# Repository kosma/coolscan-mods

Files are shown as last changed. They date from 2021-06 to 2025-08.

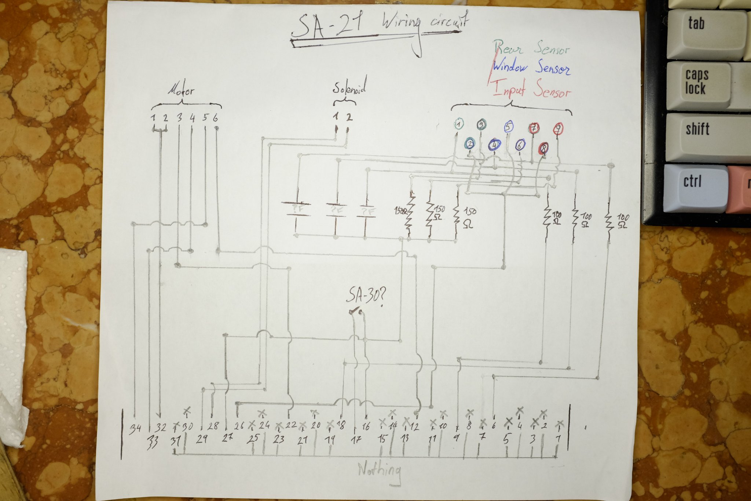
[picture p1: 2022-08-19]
doc/sa-21-30-schematic.jpg

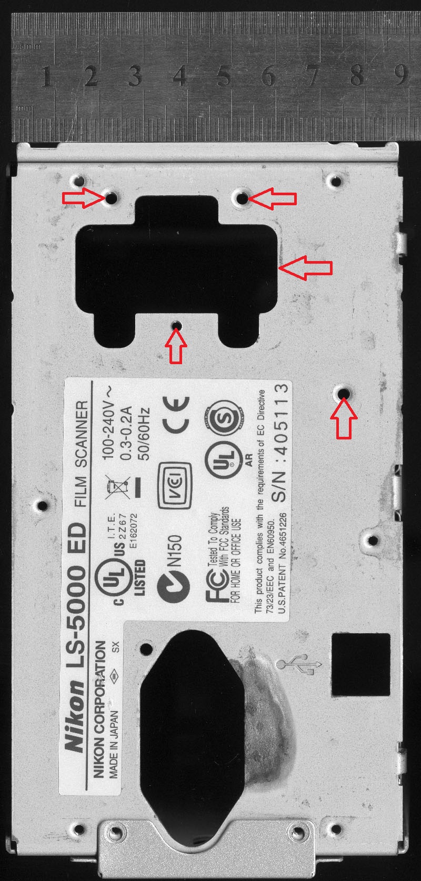
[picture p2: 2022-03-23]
hole/Modified.jpg

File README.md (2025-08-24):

# Nikon Coolscan modification project

## Adapter compatibility chart

| | **SA-30**  | **SF-200**  | **SF-210**  |
|---|---|---|---|
| **LS-40** | ✅ | ✅ | ✅ |
| **LS-50** | ✅ | ✅ | ✅ |

## Background

This project aims to extend old and unsupported Nikon Coolscan scanners.
Currently it allows owners of those scanners to unlock the ability to scan
full film rolls (using SA-30) and batch scan slides (using SF-210) on
Nikon Coolscan LS-40 and LS-50 (known as Coolscan IV and Coolscan V in
some markets).

Why? Because Nikon artificially crippled the LS-40 and LS-50 by removing
the ability to batch-scan, for no reason other than corporate greed and
market segmentation. All the logic needed to support SA-30 and SF-210 on
those scanners is already in place - it is just artificially disabled to
placate the finance and marketing.

Now, twenty years later, we can finally lift those artificial limitations
and enjoy the full power of these scanners.

## Requirements

* At the moment, this firmware is only available for LS-40 and LS-50.
* You need a 64-bit system to run the firmware updater.
* You need Vuescan drivers for the updater to work. I have not tested them
  on any other drivers. It *might* work with Nikon drivers.
* You must not have any other scanners connected during the update process.
* You must not have any scanning software running during the update process.
* For scanning entire rolls of film you need a hole cut in the back of
  the scanner. Trying to load an entire roll without the hole cut will
  cause physical damage to the film and/or scanner. The hole is not needed
  for bulk slide scanning with SF-200/SF-210.

## Instructions

1. Download the latest firmware package from the [Releases](https://github.com/kosma/coolscan-mods/releases) section and unpack it.
2. Connect your LS-40 or LS-50 over USB. Turn on the scanner.
3. Double-click `coolscan-updater.exe` and wait for the process to complete.
   As with all firmware updates, do NOT interrupt it until it says it's done.
   You might get a SmartScreen warning - it's a false positive. Check the file
   on VirusTotal if you're suspicious.
4. Turn the scanner off and on again.
5. Congratulations! Your scanner can now accept SA-30 and SF-210.

There is a bit more of mechanical work involved if you want to scan long
strips of film (longer than six frames, and up to 40 frames):

1. Cut a hole in the back of the scanner. This requires extensive disassembly
   of the scanner, as all electronic and mechanical components inside have to
   be removed before you can safelly cut/drill an opening.
   Do **NOT** attempt to cut the hole with the components still inside - getting
   *any* metal shavings inside the scanner pretty much dooms it to fail sooner
   than later.

   For cutting the opening, use [these guides](hole/) - make sure to print
   at 100% scale! The shape of the opening accommodates a standard
   LS-4000/LS-5000 back door and a spool holder; if you don't want to install
   them (you really don't need it), you can make the shape of the opening much
   simpler. On my scanner, I used a drill and a hacksaw - the results are
   not pretty, but it works like a charm.
   
   See [Gleb's website](http://www.shtengel.com/gleb/nikon_coolscan_4000_disassembly_and_scanhead_gear_repair.htm)
   for important disassembly notes.

2. Modify your SA-21 to be an SA-30 - the conversion process is described in
   many places on the internet, e.g. [Gleb's website](http://www.shtengel.com/gleb/converting_nikon_sa21_to_sa30.htm).
   It involves nothing more than installing/soldering one jumper.

**Warning:** At the moment the SA-30 support on LS-40 is somewhat broken -
the adapter is correctly identified but you can't scan more than six frames.

In the future I will also offer 3D-printable designs for the film door and
front and rear takeup spools - but those projects are still in development.
In the meantime, consider the absolutely stunning [full roll conversion kit](https://www.etsy.com/pl/listing/949217792/nikon-4000ed-and-5000ed-full-roll)
that should also fit your modded LS-40 or LS-50.

## Risks

There are a few risks involved with installing and using modified firmware:

1. If the firmware update process goes wrong, your scanner might be left in
   a non-operational (bricked) state. In most cases you can recover from this
   by simply restarting the update procedure - but in rare cases it might be
   required to desolder the FLASH chip from the mainboard and reprogram it in
   an external programmer (e.g. TL866II). Such services are commonly offered
   by respectable electronics repair shops for a modest fee. Full firmware
   dumps are provided for this purpose in the [dumps](dumps/) directory.

2. Using the unsupported LS-30 and SF-210 adapters might cause some components
   to wear out faster. I have not identified any potential components that are
   not fit to handle a bulk adapter, but again - I might have missed something.

3. Running SA-30 with long strips of film without cutting a hole in the back
   of the scanner will cause physical damage... I don't think I have to explain
   why. As a precaution, do *not* perform the SA-21 to SA-30 conversion until
   you have the hole cut.

## Technical documentation

This information is only relevant for people working on scanners - be it modders
or repairmen. It is of not much use to general public.

* [Technical information about the mod](doc/mod.md)
* [Hardware overview](doc/hardware.md)
* [SA-21/SA-30 pinout](doc/sa-21-30.md)
* [Firmware overview](doc/firmware.md)
* [Communication protocol](doc/protocol.md)
* [Firmware updates](doc/updates.md)
* [Service Manuals](manuals/)
* [Datasheets](datasheets/)
* [Firmware dumps](dumps/)
* [Firmware reflashers](reflashers/)

## Acknowledgements

This project has been made possible thanks to some great people:

* [Gleb Shtengel](http://www.shtengel.com/gleb/index.htm) - provided knowledge, firmware dumps, USB dumps, and parts
* [Kilian Dolan](https://github.com/arahowerya) - solved the six frame mystery ([issue #4](https://github.com/kosma/coolscan-mods/issues/4))
* Victor Gerasimov - provided knowledge, ideas, and firmware dumps
* Paulo Meireles - provided hardware, inspiration, and smiles
* Graeme Hardie - provided wisdom on the value of shipping 32-bit executables
* [Nikon Coolscan Users](https://www.facebook.com/groups/1514948298527146) - provided a fantastic captive audience for my shenanigans
* [SANE](https://gitlab.com/sane-project/backends/-/blob/master/backend/coolscan3.c) - provided bad but working open driver implementation
* [Служба НТИ](https://www.snti.ru/) - provided cheap ISO/IEC standards
* Frank Phillips - said he's skeptical, giving me the best motivation possible: spite

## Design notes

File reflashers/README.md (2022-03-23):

# Firmware Reflashers

These are original Nikon firmware updater programs modified to allow reflashing -
that is, installing the same version of firmware that is already present. This can
help recover from corrupted firmware - a failure mode found in many scanners out
in the wild. Symptoms of this failure are:

* The scanner turns on and the LED lights up green immediately.
* The scanner is visible in the operating system.
* The scanner, nevertheless, does not *scan*.

The idea for those reflashers came from Gleb Shtengel, and he confirmed their
utility in fixing at least *some* of the faulty boards.

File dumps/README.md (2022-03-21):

# Firmware Dumps

This directory contains unmodified firmware dumps, to be used in case the original
firmware gets corrupted and the scanner must be repaired.
Use a FLASH programmer like TL866 to program those dumps into chips. It's *not*
possible to restore such a dump over USB, and as such the dumps are of limited use,
mostly to professional scanner repairmen.

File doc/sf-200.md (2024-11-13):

# SF-200

## Pinout

Measured by John Dykstra.  Connector model is Honda MR-34F.

| **Name** | **Pin** | **SF-200** |
|---|---|---|
| LED1 | 1 | Front panel LED |
| LED2 | 2 | Front panel LED |
| M-WSIG2  | 3 | n/c |
| M-RSIG2  | 4 | n/c |
| MSW10 | 5 | Ground (Adapter Bit #1) |
| MSW6 | 6 | n/c |
| MSW2 | 7 | Switch; closed = home position |
| MSW4 | 8 | n/c |
| MSW16 | 9 | n/c |
| MSW17 | 10 | n/c |
| MSW8 | 11 | n/c |
| MT3_B/ | 12 | n/c |
| MGND | 13 | n/c |
| M-WSIG1  | 14 | n/c |
| M-RSIG1  | 15 | n/c |
| MSW9 | 16 | Ground (Adapter Bit #0) |
| MSW11 | 17 | n/c (Adapter Bit #2) |
| MSW5 | 18 | n/c |
| MSW3 | 19 | Switch; open = limit position |
| MSW14 | 20 | n/c |
| MSW7 | 21 | n/c |
| MT3_A/ | 22 | n/c |
| M+5V | 23 | n/c |
| MAGND | 24 | n/c |
| M+15V | 25 | n/c |
| +5V | 26 | n/c |
| DGND | 27 | Ground (to switches) |
| MT4_1 | 28 | Motor |
| MT4_2 | 29 | Motor |
| MT5_1 | 30 | n/c |
| MT5_2 | 31 | n/c |
| +15V | 32 | n/c |
| MT3_A | 33 | n/c |
| MT3_B | 34 | n/c |

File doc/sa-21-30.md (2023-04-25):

# SA-21/SA-30

## Pinout

Measured by Mattia Stellacci, verified by Kosma Moczek. To see the schematic,
[click here](sa-21-30-schematic.jpg). Connector model is Honda MR-34F.

| **Name** | **Pin** | **SA-21** |
|---|---|---|
| LED1 | 1 | n/c |
| LED2 | 2 | n/c |
| M-WSIG2  | 3 | n/c |
| M-RSIG2  | 4 | n/c |
| MSW10 | 5 | Adapter Bit #1 (n/c) |
| MSW6 | 6 | Input Sensor |
| MSW2 | 7 | n/c |
| MSW4 | 8 | n/c |
| MSW16 | 9 | Rear Sensor |
| MSW17 | 10 | n/c |
| MSW8 | 11 | n/c |
| MT3_B/ | 12 | Film motor B- |
| MGND | 13 | n/c |
| M-WSIG1  | 14 | n/c |
| M-RSIG1  | 15 | n/c |
| MSW9 | 16 | Adapter Bit #0 (connected to DGND on SA-30, n/c on SA-21) |
| MSW11 | 17 | Adapter Bit #2 (connected to DGND) |
| MSW5 | 18 | Window Sensor |
| MSW3 | 19 | n/c |
| MSW14 | 20 | n/c |
| MSW7 | 21 | n/c |
| MT3_A/ | 22 | Film motor A- |
| M+5V | 23 | n/c |
| MAGND | 24 | n/c |
| M+15V | 25 | n/c |
| +5V | 26 | Sensor +5V |
| DGND | 27 | Ground (Digital/Sensors) |
| MT4_1 | 28 | Solenoid+ (Physically fixes adapter in scanner during use)|
| MT4_2 | 29 | Solenoid- (Physically fixes adapter in scanner during use)|
| MT5_1 | 30 | n/c |
| MT5_2 | 31 | n/c |
| +15V | 32 | Film motor center tap |
| MT3_A | 33 | Film motor A+ |
| MT3_B | 34 | Film motor B+ |

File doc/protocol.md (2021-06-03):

# Communication protocol

All Coolscans use SCSI internally - even the Firewire/USB ones.
The scanners operate using SGC-2 (SCSI Graphics Commands) with some
proprietary extensions in the form of extra opcodes. Those opcodes
can be inferred from the firmware code (SCSI dispatch tables) and/or
SANE `coolscan3.c` driver (which contains some important nuggets of
knowledge, especially about USB communication protocol).

## SCSI scanners

The flavor of SCSI is SCSI-2. The parallel bus is 8-bit and runs at 10MHz,
giving an effective transfer rate of 10MB/s or 80Mbit/s. The bus is
single-ended and operates at TTL voltage levels, making interfacing
from a simple microcontroller quite possible.

See the [Wikipedia article](https://en.wikipedia.org/wiki/Parallel_SCSI)
for a timeline of Parallel SCSI evolution.

# FireWire scanners

The protocol used is [SBP-2](https://en.wikipedia.org/wiki/Serial_Bus_Protocol_2).
This is a direct SCSI transport for Firewire devices, meaning very little
to no extra translation is needed.

# USB scanners

The USB scanners use extra framing commands to communicate SCSI phase and
sense data over USB. They use a simple bulk interface consisting of one
Bulk-Out endpoint and one Bulk-In endpoint. This makes them suitable to be
used with Windows' `usbscan.sys` driver, since the following is enough to
perform all communication with the scanner - no extra syscalls are needed:

```c
CreateFile('\\\\.\\usbscan0', OPEN_EXISTING...);
WriteFile(hScanner, data, len);
ReadFile(hScanner, data, len);
```

Based on reading the SANE source code (`coolscan3.c`) and sniffing
Vuescan's communication, the following protocol has been established:

1. Send the SCSI command block.
2. Query the current SCSI phase by sending `0xD0`.
3. Receive the status byte that indicates the current phase.
4. Perform read/write depending on the phase.
5. Once phase indicates the command has completed, read
   the SENSE data by sending `0x06` and reading 8 bytes.

The intricacies of this protocol are not yet known to me but the above
information is enough for performing basic communication with success.

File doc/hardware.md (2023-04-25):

# Hardware overview

## CPU

The CPU used in all Coolscans is H8/3003. The CPU operates in Advanced Mode
(24-bit address bus). It is supported in IDA as "Hitachi H8/300H advanced".

## Peripheral connections

The scanner contains multiple address/data buses, with ASIC sitting in the
middle of it all. Despite of this complexity, all peripherals (including
LUT RAM, USB controller, etc.) can be directly accessed from the CPU.
The ASIC takes care of asserting the correct Chip Select lines and access
arbitration.

For exact connection diagrams see LS-50 and LS-4000 Repair Manuals. Most
information in those manuals can be extrapolated to other models.

## Memory map

This is the memory map on the LS-50. Different scanners will have
subtle differences - things like smaller/dual-chip memory (LS-2000),
different communication controllers (LS-4000), etc.

| Start | End | Mapped Device | Actual Size |
|---|---|---|---|
| 0x000000 | 0x1fffff | NOR Flash (MBM29F400BC)  | 0x80000 |
| 0x200000 | 0x3fffff | ASIC? | 0x488 |
| 0x400000 | 0x5fffff | RAM | 0x20000 |
| 0x600000 | 0x7fffff | USB Controller (ISP1581) | 0x100 |
| 0x800000 | 0x83ffff | ASIC-connected RAM (DSL) | 0x40000 |
| 0xc00000 | 0xc0ffff | ASIC-connected RAM (BUF) | 0x10000 |
| 0xfffd10 | 0xffff0f | Internal RAM | 0x200 |
| 0xffff1c | 0xffffff | Peripheral Registers | 0xe4 |

The exact purpose of ASIC-connected RAM has not been determined but it's
not very important either - that RAM is used as 1. data buffer and 2. CCD
compensation. The above memory ranges were taken from `memtest_table`
(Coolscans run a memory test at boot) and they might be slightly wrong.

LS-2000 has two separate RAM chips mapped at 0x400000 and 0x600000.
How ASIC is mapped on this scanner is TBD. Note that I haven't yet done
extensive analysis on LS-2000 firmware so this information may be wrong.

## GPIO connections

Not all signals are routed on all scanners - e.g. LS-50 lacks rear sensors
but the signals are still physically present.

| GPIO | Signal Name | Peripheral |
|---|---|---|
| P77 | MSW19 | Output photointerrupter (active high)  |
| PC7 | MSW12 | Adapter detection switch (active high) |
| PC6 | MSW18 | Rear door sensor (active low) |
| PC5 | MSW11 | Adapter ID bit #2 (active high) |
| PC4 | MSW10 | Adapter ID bit #1 (active high) |
| PC3 | MSW9 | Adapter ID bit #0 (active high) |
| PB4..PB7 | MT3_\* | Film advance motor |

## Adapter IDs

Adapter ID is a three-bit value. The bits are inverted from the signals
on the GPIO lines - a line shorted to ground is 1, a line left open is 0.
The "Adapter ID" column refers to the adapter as seen by firmware.

| Adapter type | PC7 | PC5 | PC4 | PC3 | Adapter ID |
|---|-----|-----|-----|-----|---|
| No adapter | 0 | * | * | * | |
| "For inspection purposes" | 1 | 0 | 0 | 0 | 7 |
| "Not defined" | 1 | 0 | 0 | 1 | 6 |
| SA-30 | 1 | 0 | 1 | 0 | 5 |
| SA-21 | 1 | 0 | 1 | 1 | 4 |
| SF-210 | 1 | 1 | 0 | 0 | 3 |
| IA-20 | 1 | 1 | 0 | 1 | 2 |
| SA-20 | 1 | 1 | 1 | 0 | 1 |
| MA-21 | 1 | 1 | 1 | 1 | 0 |

## "For inspection purposes"

There is code that suggests that it's possible to enter recovery mode
by inserting an adapter with the ID of 7 (all ID lines pulled low).
Such an adapter probably doesn't exist "in the wild" but can be
fabricated by e.g. modifying an SA-30.

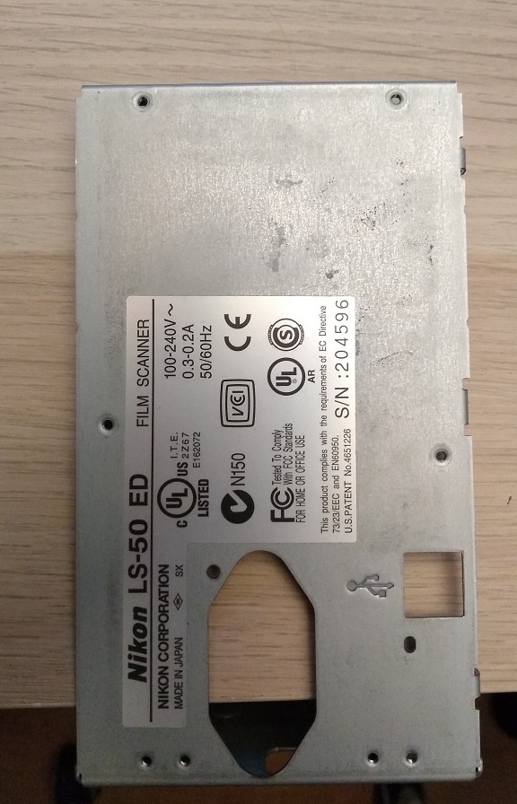
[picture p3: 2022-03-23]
hole/Original.jpg

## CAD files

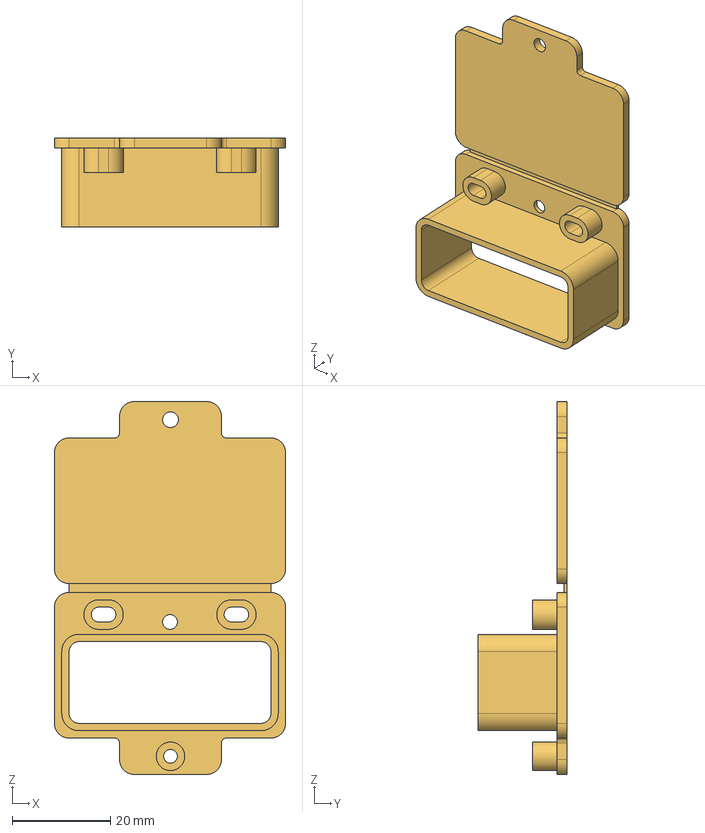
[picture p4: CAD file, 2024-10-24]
3dmodels/Film Door - With Flap.step
47.0 x 18.0 x 75.8 mm

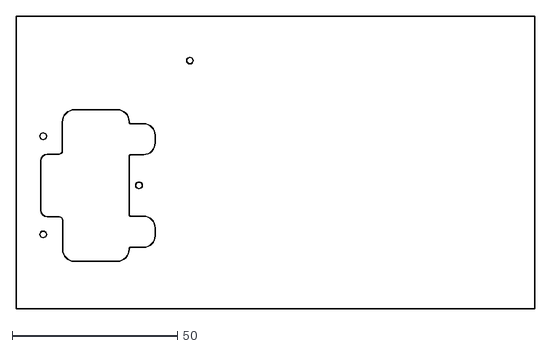
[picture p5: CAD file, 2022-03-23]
hole/LS-5000 Film Door Cutout.dxf
156.6 x 88.5

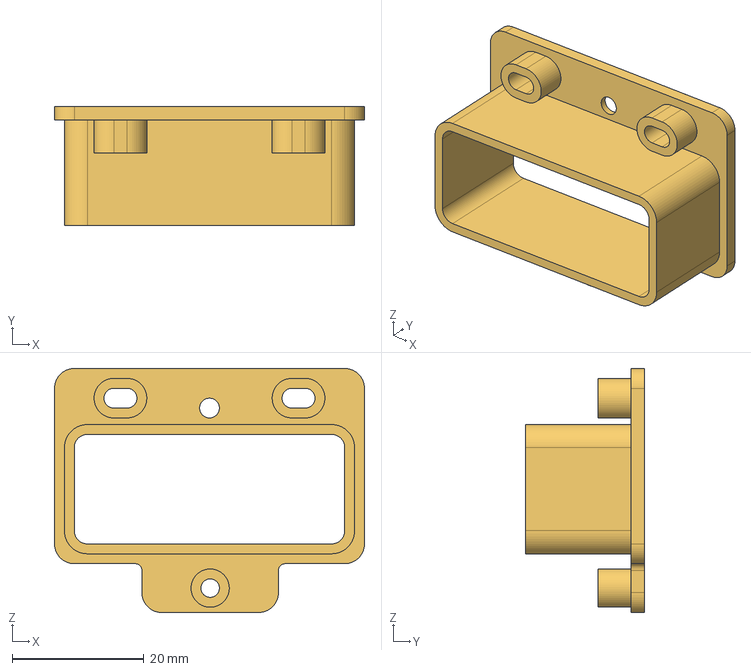
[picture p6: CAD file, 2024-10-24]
3dmodels/Film Door - No Flap.step
47.0 x 18.0 x 37.0 mm

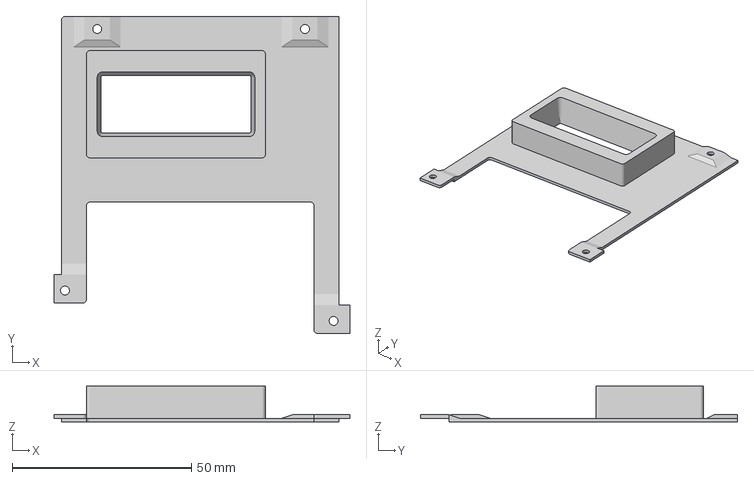
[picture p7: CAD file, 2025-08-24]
3dmodels/With screw holes/Base.3mf
82.5 x 88.5 x 10.0 mm

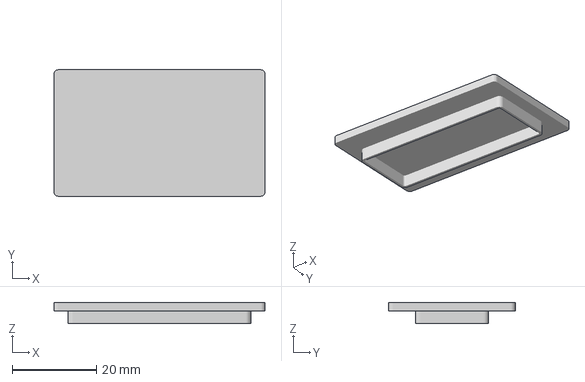
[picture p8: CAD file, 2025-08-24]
3dmodels/With screw holes/Door.3mf
50.0 x 30.0 x 5.00 mm

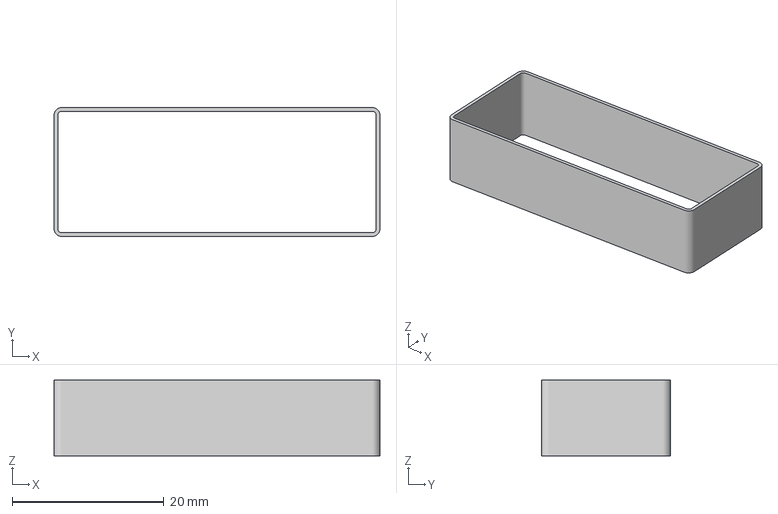
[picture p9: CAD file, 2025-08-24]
3dmodels/With screw holes/Inside tube.3mf
43.0 x 17.0 x 10.0 mm

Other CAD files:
3dmodels/With screw holes/FilmDoor2.0.f3d

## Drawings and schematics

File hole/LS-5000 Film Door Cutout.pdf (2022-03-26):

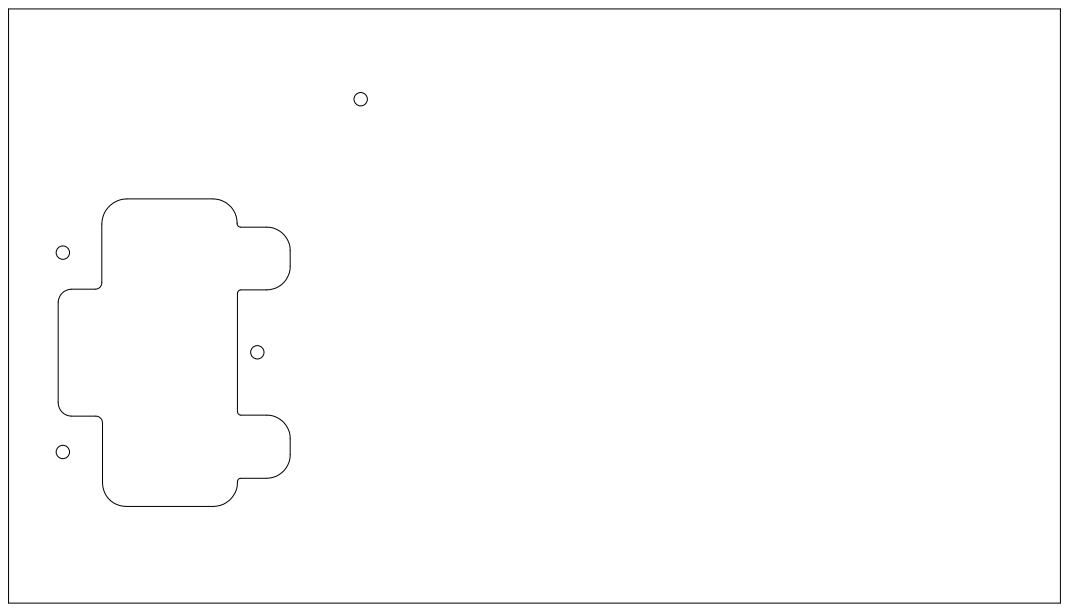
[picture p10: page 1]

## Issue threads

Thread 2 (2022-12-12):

Rear sensor on connector pin 9?

zapdogster, 2022-12-12:
In your table you have it listed as pin 8. The SA-21 schematic shows pin 9. I also measured my SA-20 and it is on pin 9.

kosma, 2023-04-25:
Fixed in 9681b58. Thanks!

Closed 2023-04-25.

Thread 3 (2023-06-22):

"Scanner could not load film"

sloaneross, 2023-06-22:
Not sure where the fault lies here, either with the firmware or some physical issue related to the cutting of the hole in the back.

I have a LS-50 ED, I have a SA-21. I followed the instructions and I can get the scanner to correctly identify that it *can* scan 40 frames. But, there's a problem.

In NikonScan any attempt to scan it pulls the film in, then ejects it with the error _The scanner could not load the film, please consult your users manual _

In VueScan trying to preview it scans about 1mm of the first frame, and uses that as the preview for everything. I'm a bit at a loss as to what is going on.

Attached are the memory dump and the error I get from nikon scan
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

sloaneross, 2023-06-22:
Update, I have gotten it working with vuescan but this software is bad. I'm not sure how but I would like to try to work on getting it working with nikonscan

Toesoe, 2023-11-01:
Same issue here. Vuescan seems to work fine, but Nikon Scan refuses to load the strip, it spits it out after trying to obtain either a preview or a 6-frame scan.

Dump:

```
***************************************
* Nikon Memory Dumper by Kosma Moczek *
***************************************
Connecting to scanner \\.\usbscan0...
...connected.
Checking model: 0x04b0, product: 0x4001, version: 2.02
...model: DF17811
Checking scanner...
cmd: 12 00 00 00 24 00
...scanner says it's a Nikon   LS-50 ED        2.02
Reading memory at 0xffffc0 to 0xffffdf...
cmd: 3c 02 00 ff ff c0 00 00 20 00
I/O Registers:
0000: ff ff 00 00 ff ff 01 00
0008: ff ff 00 ff ff ff ff eb
0010: ff ff fc 3f ff ff 00 d7
0018: 00 ff 00 00 00 00 1f ff

Finished.
Press any key to continue...
```

kosma, 2024-10-24:
Fixed in #4.

Closed 2024-10-24.

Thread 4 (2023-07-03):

Vuescan only scans 6 frames from roll

vanstinator, 2023-07-03:
I've converted an SA-21 to an SA-30 via the pin trick, and flashed the latest firmware release. Vuescan only ever scans up to 6 photos before spitting the roll back out.

Here's a memory dump. Happy to help in any way I can.

```
***************************************
* Nikon Memory Dumper by Kosma Moczek *
***************************************
Connecting to scanner \\.\usbscan0...
...connected.
Checking model: 0x04b0, product: 0x4001, version: 2.01
...model: DF17811
Checking scanner...
cmd: 12 00 00 00 24 00
...scanner says it's a Nikon   LS-50 ED        2.02
Reading memory at 0xffffc0 to 0xffffdf...
cmd: 3c 02 00 ff ff c0 00 00 20 00
I/O Registers:
0000: ff ff 00 00 ff ff 01 00
0008: ff ff 00 ff ff ff ff eb
0010: ff ff fd 3f ff ff 00 d7
0018: 00 ff 00 00 00 00 1f ff

Finished.
Press any key to continue...
```

vanstinator, 2023-07-05:
My understanding is the rear door sensor doesn't exist on the LS-50, but the sensor value is still present. Wonder if there _is_ maybe a hardware revision difference at play here.

kosma, 2023-07-06:
That's my understanding as well - the phantom sensor is on PC6/MSW18. The purpose of I/O register dump was to check if there are any differences in the input port values seen by the scanner - but so far I have not determined anything useful. I am still waiting for a friend to send me a second LS-50 board, just to compare.

vanstinator, 2023-07-06:
Having a board in person is obviously best, but if that doesn't work out I'd be happy to give you remote access to a Windows box connected to this unit if there's any value to that at all. This kind of RE is a little outside my wheelhouse but I'll help any way I can!

remigrousset, 2023-07-30:
Hey there,
I did the same, I've converted an SA-21 to an SA-30 via the pin trick, flashed my coolscan LS-50 with the Version 2.02 and got the same result...
With vuescan I can scan up to 6 images, same with NikonScan...

Sharing 2 memory dump, I got on error the first time :

```
***************************************
 * Nikon Memory Dumper by Kosma Moczek *
***************************************
Connecting to scanner \\.\usbscan0...
 ...connected.
 Checking model: 0x04b0, product: 0x4001, version: 2.02
...model: DF17811
Checking scanner...
cmd: 12 00 00 00 24 00
...scanner says it's a Nikon   LS-50 ED        2.02
Reading memory at 0xffffc0 to 0xffffdf...
cmd: 3c 02 00 ff ff c0 00 00 20 00
sense: 02 06 29 00 00 00 00 00
Error: sense_buffer data indicates failure
Press any key to continue...

 ***************************************
* Nikon Memory Dumper by Kosma Moczek *
***************************************
Connecting to scanner \\.\usbscan0...
...connected.
Checking model: 0x04b0, product: 0x4001, version: 2.02
...model: DF17811
Checking scanner...
cmd: 12 00 00 00 24 00
...scanner says it's a Nikon   LS-50 ED        2.02
Reading memory at 0xffffc0 to 0xffffdf...
cmd: 3c 02 00 ff ff c0 00 00 20 00
I/O Registers:
0000: ff ff 00 00 ff ff 01 00
0008: ff ff 00 ff ff ff ff eb
0010: ff ff fc 3f ff ff 00 d7
0018: 00 ff 00 00 00 00 1f ff

Finished.
Press any key to continue...
```

Let me know if I can help anyhow.
And thanks again for putting all the work together!

sloaneross, 2023-09-18:
> Hey there, I did the same, I've converted an SA-21 to an SA-30 via the pin trick, flashed my coolscan LS-50 with the Version 2.02 and got the same result... With vuescan I can scan up to 6 images, same with NikonScan...

I can't get nikonscan to work at all with the SA-30 pin trick, but vuecan does. @kosma, right now my LS-50 is just sitting. I'd post it over to you to fiddle with if that would help (assuming you'll send it back at some point if you get this working)

snowphish, 2024-03-14:
Dang mine is doing the same, cut the hole, shorted the pins, flashed the firmware, scans 6 then ejects the film

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

hohaha045, 2024-04-12:
Same issue with mine, I think A-30 is identified correctly (there are 40 frames showing in Vuescan) but eject after frame 6)

```
***************************************
* Nikon Memory Dumper by Kosma Moczek *
***************************************
Connecting to scanner \\.\usbscan0...
...connected.
Checking model: 0x04b0, product: 0x4000, version: 2.02
...model: PT17035
Checking scanner...
cmd: 12 00 00 00 24 00
...scanner says it's a Nikon   LS-40 ED        2.02
Reading memory at 0xffffc0 to 0xffffdf...
cmd: 3c 02 00 ff ff c0 00 00 20 00
I/O Registers:
0000: ff ff 00 00 ff ff d1 00
0008: ff ff 00 fb ff ff 7f eb
0010: ff ff fc 3f ff ff 01 d5
0018: 00 ff 00 00 00 00 1f ff

Finished.
Press any key to continue...

```

snowphish, 2024-04-12:
Yeah, I've tried a few things on the hardware side also.

Assuming it might be a sensor issue as the 4/5000 models have an extra sensor for the back door - I tried messing with PC6 on the H8 ic ... didn't do anything

seems there is also a photosensor on the other models, tried playing around with that pin as well but I imagine it would be looking for a signal and not just a simple pull-up pull-down on that pin...

out of ideas, if anyone has leads - I'm down to experiment

Toesoe, 2024-04-12:
@snowphish lmk if you want to take a deeper look at this, I tried patching out the checks on PC6 in the firmware (see the other open issue) but didn't get anywhere. who knows there's something else to figure out here, maybe if someone's got a 4000 to mess around with to compare signals?

hohaha045, 2024-04-12:
Anyone tried with the real "SA-30"?

arahowerya, 2024-10-01:
Hey everyone, been doing this mod to my LS-50 today and having the same issue.

If PC6 is the rear door input pin, how come the data direction register for port C (PCDDR) is set to 0xFF on all the above examples?

that would indicate it's set as an output... So surely it would need to be set as an input first? Or am I missing something?

@kosma what does your (working!) LS-50 say? Do you have a register dump handy?

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

p.s. this repo is excellent, very impressive work so far

arahowerya, 2024-10-01:
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
... nevermind - read the datasheet Kilian 😅

arahowerya, 2024-10-01:
I just put a bit of magnet wire to short PC6 (pin 17) to GND - and it wouldn't initiate USB at all. Nothing detected on two computers.

Removed the short and it came back to life. Weird. It definitely wasn't shorting on any other pins either

arahowerya, 2024-10-01:
Also fwiw

```
***************************************
* Nikon Memory Dumper by Kosma Moczek *
***************************************
Connecting to scanner \\.\usbscan0...
...connected.
Checking model: 0x04b0, product: 0x4001, version: 2.02
...model: DF17811
Checking scanner...
cmd: 12 00 00 00 24 00
...scanner says it's a Nikon   LS-50 ED        2.02
Reading memory at 0xffffc0 to 0xffffdf...
cmd: 3c 02 00 ff ff c0 00 00 20 00
I/O Registers:
0000: ff ff 00 00 ff ff 01 00
0008: ff ff 00 ff ff ff ff eb
0010: ff ff fc 3f ff ff 01 d7
0018: 00 ff 00 00 00 00 1f ff

arahowerya, 2024-10-01:
I realised I got the pin1 marking incorrect earlier so re-did the modification to pull PC6 down (with the right pin this time)!

You can see it in the registers - `d7` goes to `97`

```I/O Registers:
0000: ff ff 00 00 ff ff 01 00
0008: ff ff 00 ff ff ff ff eb
0010: ff ff fc 3f ff ff 02 97
0018: 00 ff 00 00 00 00 1f ff
```
but it still only scans 6 frames in the roll unfortunately

arahowerya, 2024-10-01:
Final update from me
Apologies if this is causing email spam
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
kosma, 2024-10-12:
Yes - the dump in the repository is from my scanner.

andreassloth, 2024-10-13:
> When you ran it on the 4000 - did you have the rear door opened? On my LS-50 it scanned 7 frames then kept scanning but advanced 3 sprockets Into the 8th and no further.

Door Opened. When the door is closed, It refuses to advance but doesn't eject the film as it does when the perforation sensor if disconnected.

arahowerya, 2024-10-13:
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
Mine is much like the "other" one - with the 1S015-146 on the bottom side of the board on the silkscreen

kosma, 2024-10-13:
From our group expert Gleb Shtengel:

> I have seen different versions of 9000 and 5000 motherboards. As you know, Nikon went through a redesign mid-way through the production of the 50, 5000, and 9000 units. Mostly cost-cutting, I believe. (It is thanks to that redesign, that we have the lousy SANSHIN power supplies). The units (all three models) before redesign have serial numbers starting with 2XXXXX, after redesign it was 3XXXXX or 4XXXXX. In your photo I see that one motherboard 204596 on it. If that is the serial number - it is from the early run (before redesign). The other has 415123. Again if it is the serial number, than it is a late production, after re-design. I would expect these to have different motherboards, like in 5000 and 9000 units.

andreassloth, 2024-10-13:
> From what I can tell so far, it all boils down to bit 3 in `0x4062da`

Sound's like we're digging around the same general area.

I've also found that bit 3 of `0x4062da` gets set or cleared based on the ADC value at the end of the function that starts a `0x00032f3e` (in the full LS50 flash dump from Kosma).

The function gets called based on the value in ram address `0x400773` in a switch case over various sensor checks on address `0x0002aedc`

I'm still trying to find the loop that dispatches the checks and validates the timing of `0x4062da`. I'll keep you posted

arahowerya, 2024-10-13:
Great. I've been running the same preview scans etc through silverfast and Vuescan while attached to the logic analyser. If you want any hardware probed/tested let me know what and I'll run the test and send you results.

I'm concentrating on this 3 sprocket problem. I only noticed now that the 3 sprockets makes the end of the strip juuuuuust line up with where the hole is cut! There must be some second level failsafe here that we're missing.

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

Here you can see the (bad photo sorry) end of the film strip just beside the end of the film transport - this is where the error and rapid LED blink happens and it spits it back out again.

kosma, 2024-10-13:
I suspect the second failsafe is the rear door sensor connected to PC6 (I think? that's what my docs say, might be worth verifying) - the scanner will refuse to proceed past that point if it knows the door is closed, as that would lead to physical damage.

arahowerya, 2024-10-13:
Don't think so - I have PC6 pulled to GND
Verified here register 0xFFD7 =  0x97 =  bit 6 - LOW

```
I/O Registers:
0000: ff ff 00 00 ff ff 01 00
0008: ff ff 00 ff ff ff ff eb
0010: ff ff fc 3f ff ff 01 97
0018: 00 ff 00 00 00 00 1f ff

andreassloth, 2024-10-13:
@arahowerya I'm pretty sure the door swtich on my LS4000 shorts to GND when closed. Unfortunately, I cannot check right now.  Give it a go without shorting PC6 to GND.

arahowerya, 2024-10-13:
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

HOLY CRAP IT WORKED!!

I have msw19 (rear photo interrupter) shorted to msw5 (centre)

arahowerya, 2024-10-13:
I think next I will try and upload a binary that changes any references to register `#0xFFE6` (ADDRDH) (AN7) to `#0XFFE0` (ADDRAH)

Which will be the equivalent of shorting the pins as I have.

The reason I chose MSW5 is because if you look at the hole where the rear sprocket is, it is in the same "phase" as the centre sprocket hole. The 3 other sensors (Front Centre Back) are slightly out of phase with one another as you can see in this plot from the logic analyser. MSW5 is most in phase with the rear.
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

kosma, 2024-10-13:
You have no idea how much joy this brings me. Not just the results - but also the very fact that some people on the internet decided to tackle the same problem and progressed further. Not being alone when battling something is the best feeling in the world! ✨ 🥰

arahowerya, 2024-10-13:
The joy is truly mutual, thank you so much for the serious effort so far.

Put together the changes but
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

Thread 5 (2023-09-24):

Modifying frame boundary detection?

mabunday, 2023-09-24:
Just stumbled upon this project and curious if anyone has tried modifying the frame boundary detection algorithm as that seems like a major weak point of the NikonScan software.

I frequently notice that the thumbnail previews are able to find the correct film boundaries when doing full roll scans, but struggle when refocusing for preview or full scans of individual frames. Seems like there's a difference/flaw in how the thumbnails are positioned vs the preview/scans and I'm wondering if anyone else has tried to fix this in the software...

Archilokos, 2024-09-28:
This could be especially useful when scanning negatives as positives to convert them in inversion applications nike Negative Lab Pro or ColorPerfect.

For whatever reasons, the frame boundaries detection works pretty well when scanning negatives as negatives, but if you switch to positives after the preview, it resets the detection and starts all over again, messing up the detection. You have to play with the offset tool for a while to set the 36 pictures. A pain.

I am not sure something can be done at this point. The Nikon Scan source code is probably on some backup CDs somewhere in a Nikon office drawer. Or lost.

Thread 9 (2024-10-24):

Firmware mod for upgrading SA-21 to SA-30

kosma, 2024-10-24:
There is some potentially low hanging fruit to figure out: it should be possible to patch the firmware of all "modern" 35mm scanners (LS-40, LS-4000, LS-50, LS-5000) to treat all SA-21 as SA-30, without having to mod the adapter. If anyone feels brave - that would be greatly appreciated and would maybe help Frank's mood a bit. ;)

hohaha045, 2024-10-25:
@kosma I own a ls-40, and will try the new 2.03 firmware to see if it also work for it.

Archilokos, 2024-11-01:
I tested the 2.03 firmware with my LS-40. It doesn't work unfortunately. Let me know if I can do something to help.

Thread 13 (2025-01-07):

Need to replace miniature switch in 8000 flap

easdale, 2025-01-07:
Do you know what miniature switch is used in Nikon Coolscan LS8000 flap door. I need to replace it but can't find a part number that is useful to get a new replacement for it. Thanks

kosma, 2025-01-08:
I think the common wisdom is just to the the wires together and continue living a happy life. You can try replacing it but it's not too worth of an effort...

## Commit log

2022-03-26 add correct hole pdf
2022-08-19 add sa-21/30 schematic
2022-08-19 add SA-21 connector model
2022-09-02 Touched up tabular pinout for SA-21: Fixed error in explanation of pin 16/17 in chart, changed name and annotated solenoid pin with explanation of purpose
2024-10-14 Change ADC source for rear photointerrupter check to AN4
2024-10-24 coolscan-memory-dump: include ADC registers
2024-10-24 3dmodels: add film door with and without the flap
    [Film Door - No Flap.step, Film Door - With Flap.step]
2024-11-13 Add SF-200 pinout table.
    Add pinouts for the SF-200 slide feeder, traced on serial #208280.
2024-11-26 added WIP film door models
    [Base.3mf, Inside tube.3mf]
2024-11-27 add door
    [Door.3mf]
2024-11-27 add Fusion source file
    [FilmDoor2.0.f3d]
